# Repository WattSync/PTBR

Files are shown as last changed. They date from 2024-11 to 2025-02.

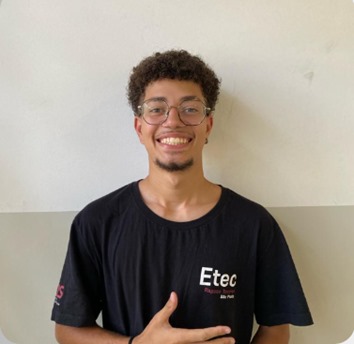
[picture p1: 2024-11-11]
Website/imagens de perfil/perfil bruno.jpg

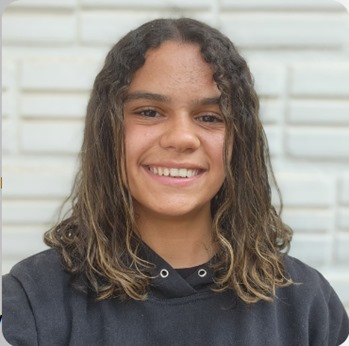
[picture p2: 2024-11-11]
Website/imagens de perfil/camilinha foto.jpg

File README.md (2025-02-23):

# WattSync - Wattímetro Inteligente

O WattSync é um projeto de desenvolvimento de um wattímetro multifuncional que visa atender à crescente demanda por tecnologias de medição e gerenciamento de consumo elétrico em residências. Este dispositivo foi projetado para promover segurança, praticidade e eficiência, oferecendo uma série de funcionalidades que auxiliam no controle do uso de energia.

## 📋 Objetivo do Projeto
Desenvolver um dispositivo capaz de monitorar o consumo de energia elétrica em residências brasileiras, proporcionando acessibilidade e promovendo o controle de gastos com foco em sustentabilidade. O WattSync é voltado para auxiliar os usuários no entendimento e gerenciamento de seu consumo energético, além de fornecer recursos para desligamento remoto e proteção contra sobrecargas.

### Funcionalidades
- Medição de corrente, tensão, potência e frequência com precisão.
- Monitoramento remoto via aplicativo com conexão Wi-Fi.
- Indentificação do tipo de rede elétrica.
- Desligamento automático em caso de sobrecarga.
- Desligamento automático em caso de subtensão ou sobretensão.
- Aviso sonoro em caso de desligamento.
- Limite de consumo configurável.
- Display para a visualização dos dados no própio dispositivo.
- Programação de horários para ligar e desligar os dispositivos.
- Interface amigável para visualizar e interpretar dados de consumo.
- Pode ser utilizado em todas as redes elétricas brasileiras.
## 🛠️ Tecnologias Utilizadas

### Hardware
- **Microcontroladores:** ESP32S3 (WROOM 1) e ATmega328P.
- **Sensores de Corrente e Tensão:** ACS712 30A e Divisor de Tensão.
- **Componentes de Proteção:** Varistor 14D561K, Fusível de Queima Rápida de 25A e Diodo Zener 1N4733A.

### Software
- **Frontend do Aplicativo:** Flutter.
- **Backend:** C (para o ESP32 e ATmega328P).
- **Armazenamento de Dados:** SQLite para o aplicativo.
- **Ferramentas de Design:** Canva, Figma, Paint, Fritzing, KiCad, Astah UML.
- **IDE:** Visual Studio Code, Arduino IDE, Google IDX.
- **Versionamento de Código:** Git, Github.

## 🚀 Como Executar o Projeto

### Pré-requisitos
- [Flutter SDK](https://flutter.dev/docs/get-started/install) para o aplicativo.
- [Arduino IDE](https://www.arduino.cc/en/software) para o ESP32 e ATmega328P.

### Passos para Configuração
1. Clone este repositório:
    ```bash
    git clone https://github.com/usuario/WattSync.git
    cd WattSync
    ```

2. Configure o ambiente de desenvolvimento Flutter:
    ```bash
    flutter pub get
    ```

3. Conecte o ESP32 ao computador e faça upload do código na pasta `ESP32S3` para o ESP32S3 usando a Arduino IDE.
    Selecione a placa "ESP32S3 Dev Module", em outras variações pode não funcionar corretamente.

4. Conecte o ATmega328P ao computador utilizando um gravador UART e faça upload do código na pasta `ATMEGA328P` usando a Arduino IDE.

5. Execute o aplicativo:
    ```bash
    flutter run
    ```

6. No aplicativo, insira o código do produto para acessar as funcionalidades de monitoramento e controle.

## 💡 Estrutura do Projeto

- `app/`: Código do aplicativo Flutter, incluindo widgets e gráficos.
- `wattmeter/ESP32S3/`: Código para o ESP32, responsável por capturar os dados do ATmega328P e enviar ao aplicativo.
- `wattmeter/ATMEGA328P/`: Código para o ATmega328P, responsável por realizar a leitura, calcular os valores e enviar para o ESP32S3.
- `docs/`: Documentação do projeto, incluindo diagramas UML, Canvas do modelo de negócios e relatórios.

Desenvolvido por [Equipe WattSync](https://github.com/WattSync) para o Trabalho de Conclusão de Curso do Técnico em Desenvolvimento de Sistemas da ETEC Raposo Tavares.

### 👷👷‍♀️ Membros da Equipe

- [Beatriz Bernardes](https://www.linkedin.com/in/beatrizbernardess): Responsável pelo desenvolvimento do software e das apresentações.
- [Bruno](https://github.com/usuario/WattSync): Responsável pelo desenvolvimento do website.
- [Camila](https://www.linkedin.com/in/camila-lourenco23032007): Responsável pelo desenvolvimento do software e documentação do projeto.
- [Hércules da S. Pereira](https://www.linkedin.com/in/herculessp): Responsável pelo desenvolvimento e planejamento do software e hardware do dispositivo.
- [Keven Wanne](http://www.linkedin.com/in/keven-wanne): Responsável pelo desenvolvimento do software.
- [Yasmin E. P. da Silva](https://www.linkedin.com/in/yasminpilla): Responsável pelo desenvolvimento do software e documentação do projeto.

## 📝 Licença

Este projeto está licenciado sob a Licença GPL-3.0. Veja o arquivo [LICENSE](./LICENSE) para mais detalhes.

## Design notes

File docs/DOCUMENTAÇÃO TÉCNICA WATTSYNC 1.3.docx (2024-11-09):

TRABALHO DE CONCLUSÃO DE CURSO (TCC)

WATTSYNC

DOCUMENTAÇÃO TÉCNICA DO DISPOSITIVO

(VERSÃO 1.3)

São Paulo – SP

2024

O presente documento não se trata da monografia oficial do trabalho de conclusão de curso, portanto, não se faz necessário a utilização da formatação da Associação Brasileiras de Normas Técnicas (ABNT), entretanto, será utilizada parcialmente com o objetivo de facilitar a organização.

# 1 Componentes gerais

## 1.1 Capacitor

Um capacitor é um componente que armazena energia elétrica em um campo elétrico, consistindo em duas placas condutoras separadas por um material isolante. Ele é utilizado para filtrar ruídos, suavizar flutuações de tensão e armazenar energia em circuitos. A capacitância, medida em farads (F), determina a quantidade de carga que o capacitor pode armazenar e sua capacidade de desacoplamento.

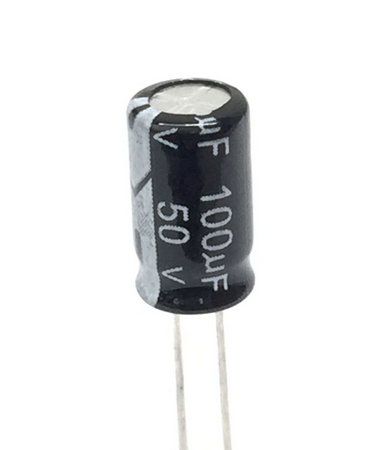
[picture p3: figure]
Capacitor Eletrolítico 100uF 50V

Figura 1 - Capacitor.

## 1.2 Resistor

Um resistor é um componente que oferece resistência ao fluxo de corrente elétrica. Ele é utilizado para limitar a corrente, dividir tensões e proteger componentes sensíveis. Os resistores têm valores de resistência, medidos em ohms (Ω), e podem ser fixos ou variáveis, permitindo ajustes em circuitos.

Figura 2 - Resistor

## 1.3 Trimpot

Um trimpot, ou potenciômetro de ajuste, é um resistor variável ajustável manualmente. Ele é utilizado em circuitos para calibrar e ajustar parâmetros, como níveis de tensão. Trimpots são menores e têm um mecanismo de ajuste que permite a regulagem com uma chave de fenda, facilitando ajustes finos.

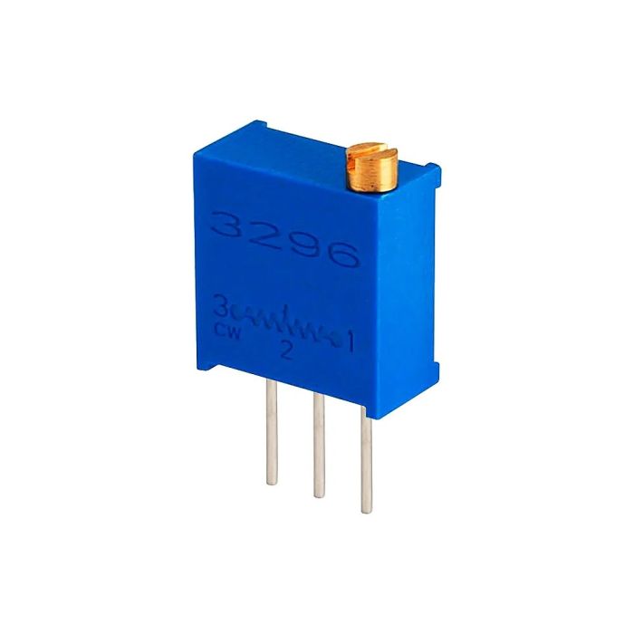
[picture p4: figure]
Trimpot Multivoltas 25 Voltas 3296W Vertical 500R Ohm

Figura 3 – Trimpot.

## 1.4 Diodo

Um diodo é um componente eletrônico que permite que a corrente elétrica flua em uma única direção, funcionando como uma válvula. Ele é usado em circuitos para retificação, proteção contra polaridade reversa e controle de sinais. Um diodo tem dois terminais: ânodo (positivo) e cátodo (negativo). Ele conduz corrente quando a tensão no ânodo é maior que no cátodo.

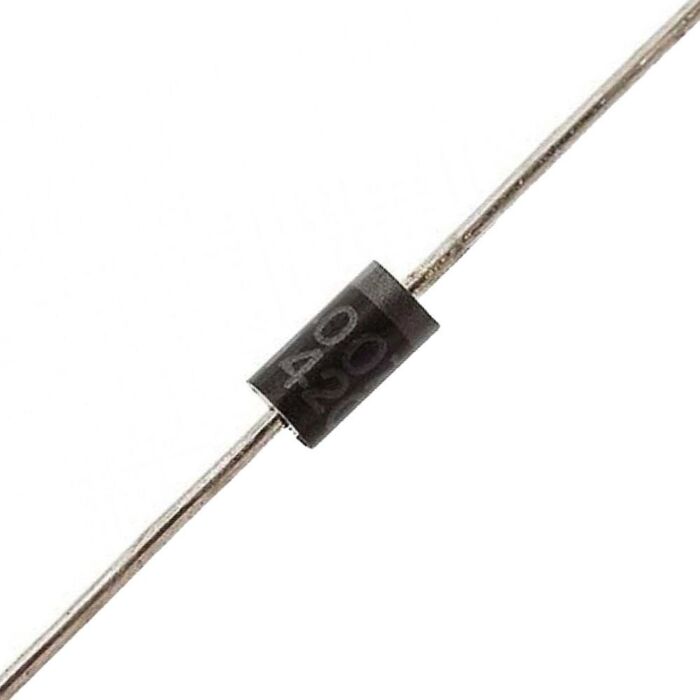
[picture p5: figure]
Componentes Eletrônicos você encontra aqui na Mamute Eletrônica | Diodo Retificador 1N4937 DO-41 600V 1A.

Figura 4 - Diodo.

### 1.4.1 Diodo Zener

O diodo Zener é uma variação do diodo projetado para operar em polarização reversa, permitindo a condução de corrente quando a tensão reversa atinge um nível específico, chamado tensão Zener. Ele é usado como regulador de tensão em circuitos, garantindo que a tensão permaneça constante, mesmo com variações na entrada. É fundamental em circuitos de proteção e estabilização.

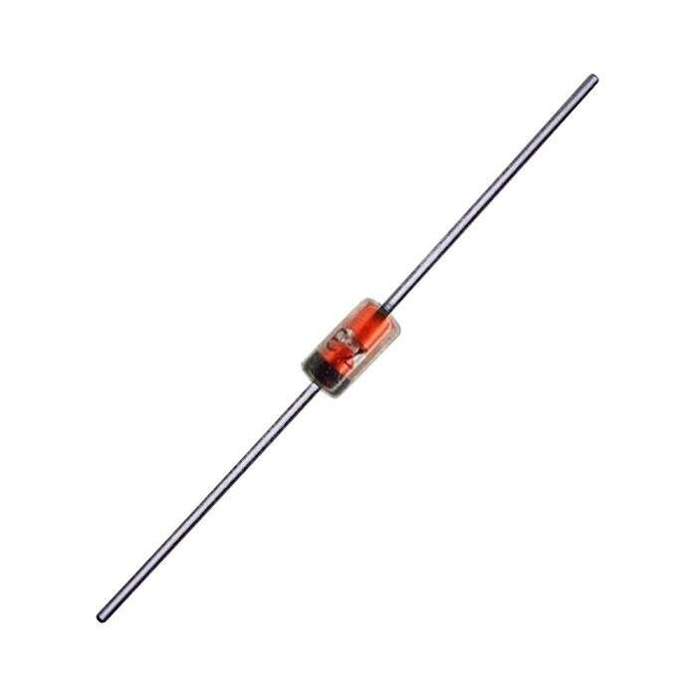
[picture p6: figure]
Diodo zener 1/2w - 5v1

Figura 5 - Diodo Zener.

## 1.5 Transistor NPN

Um transistor NPN é um tipo de transistor bipolar formado por três camadas semicondutoras: duas de material tipo N (negativo) e uma de material tipo P (positivo). Ele possui três terminais: Coletor (C), Base (B) e Emissor (E). O funcionamento do transistor NPN se baseia na polarização da base, que controla a corrente entre o coletor e o emissor. Quando a base é polarizada positivamente, ela permite que uma corrente maior flua do coletor para o emissor, funcionando como um amplificador de sinal.

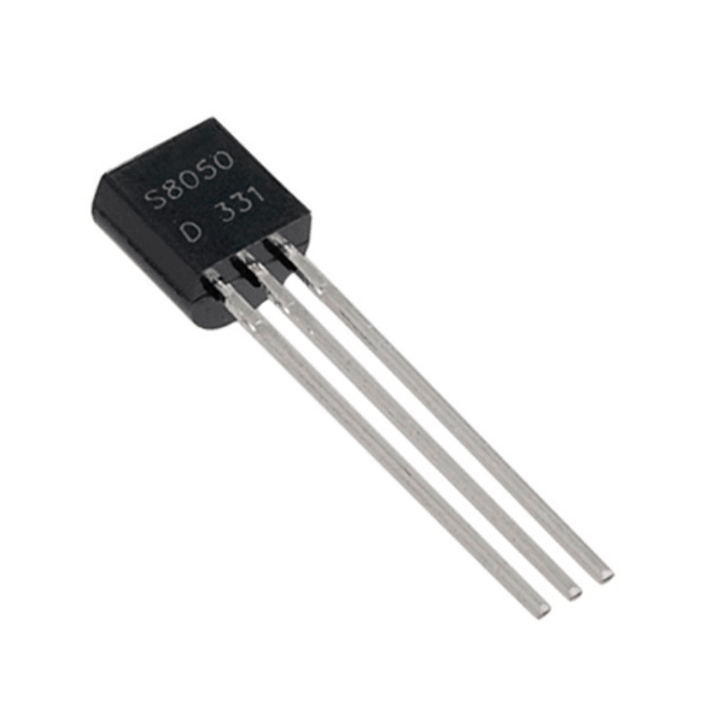
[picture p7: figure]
Transistor NPN S8050 TO-92 (PTH)

Figura 6 - Transistor NPN.

# 2 sistema de alimentação

## 2.1 Fonte de alimentação

Para que o projeto funcione, é necessário transformar a tensão alternada da tomada em baixa tensão contínua, para isso é utilizado a fonte de alimentação Hi-Link HLK-5M05, sendo bivolt, funcionando com tensão entre 100 e 240 volts, com saída de 5 volts e 1 ampère.

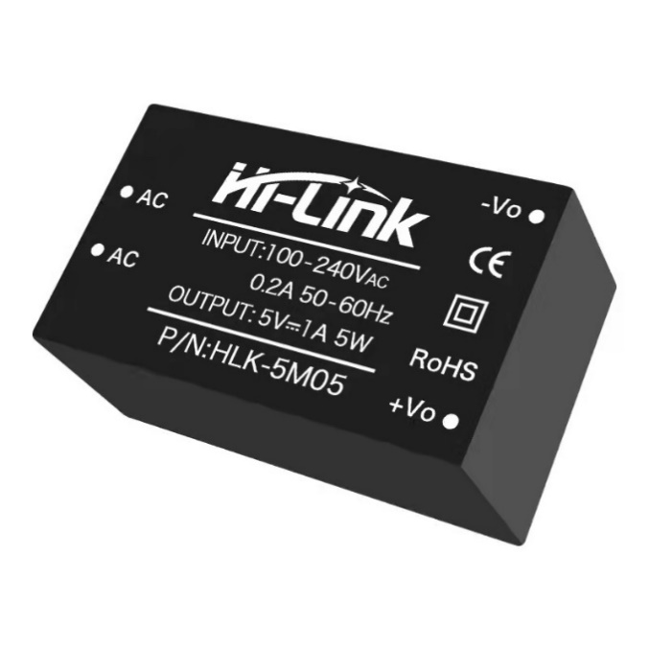
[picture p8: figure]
Mini Fonte Conversora Ac/dc Hi-link Hlk-5m05 5v 5w

Figura 7 - Fonte de alimentação HLK-5M05

## 2.2 Regulador de tensão

Dada a necessidade de garantir que a tensão de funcionamento de alguns componentes permaneça dentro dos limites adequados, é essencial implementar um sistema de regulação de tensão. Para isso, foi escolhido o regulador de tensão 3.3V AMS1117, conhecido por sua alta eficiência e capacidade de fornecer uma saída estável. Para estabilizar a tensão, foi adicionado um capacitor eletrolítico de 300uf antes do regulador e um de 100uf pós regulador.

Figura 8 - AMS1117.

## 2.3 Varistor

Para a proteção do circuito contra sobretensões, foi utilizado um varistor 14D561K, instalado entre a fase e o neutro. Este componente é projetado para absorver picos de tensão, desviando correntes excessivas para o outro condutor e, assim, protegendo os circuitos e dispositivos conectados. O varistor atua como uma barreira, evitando que tensões acima de um certo limiar atinjam componentes sensíveis, o que é crucial para garantir a integridade e a durabilidade do sistema. A escolha do varistor 14D561K se baseia em sua tensão de ruptura ser a mais próxima da necessária, proporcionando uma camada adicional de segurança ao circuito.

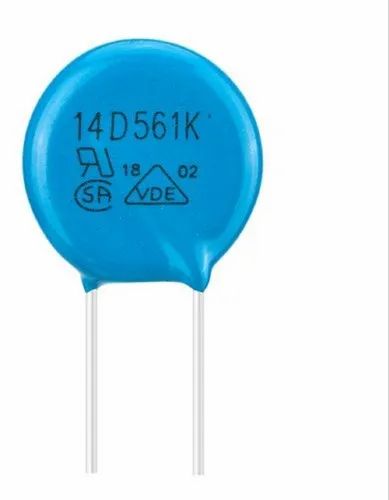
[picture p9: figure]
600V RMS HEL-14D561K at Rs 2/piece in Mumbai | ID: 2853572355062

## 2.4 Fusível

Caso o varistor atue ou a proteção eletrônica presente no dispositivo seja acionada, o fusível se rompe, desconectando o circuito e prevenindo danos aos componentes. Para essa aplicação, foi escolhido um fusível de queima rápida de 25A, dimensionado para as necessidades do projeto. Este tipo de fusível é projetado para reagir rapidamente a sobrecargas e curtos-circuitos, interrompendo imediatamente o fluxo de corrente.

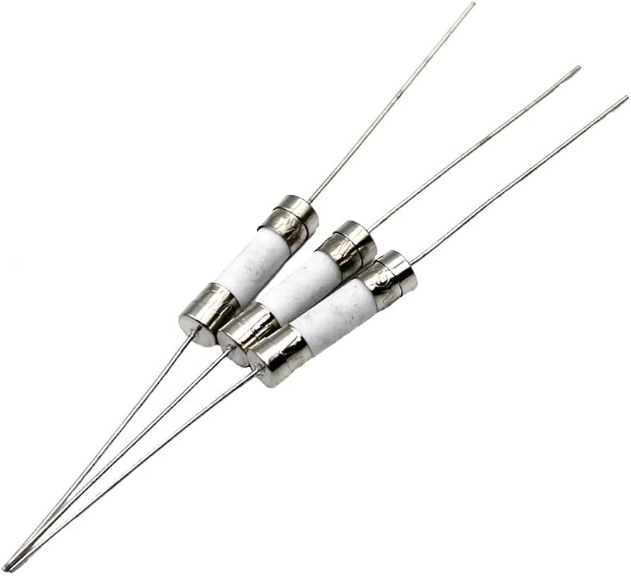
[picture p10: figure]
10PCS 5 * 20mm Ceramic Fuse with a pin 250V,Fast Break F,25A : Amazon.com.au: Home Improvement

Figura 9 - Fusível 25A

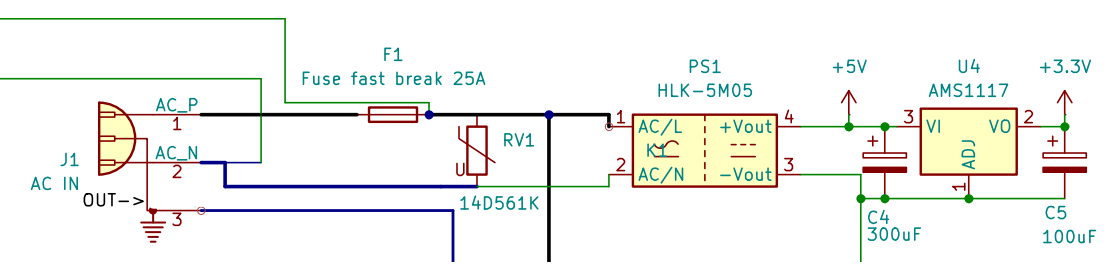
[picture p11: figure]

Figura 10 - Esquema de ligação do sistema de alimentação.

# 3 sistema de conexão e exibição

## 3.1 Microcontrolador

O microcontrolador utilizado no desenvolvimento do projeto é o ESP32 WROOM-1, um módulo altamente eficiente, com 45 portas GPIO (General Purpose Input/Output), permitindo uma ampla gama de funcionalidades, como controle de periféricos externos, sensores e atuadores. Ele também suporta modulação por largura de pulso (PWM), permitindo o controle preciso de dispositivos como motores, LEDs e outros componentes. O ESP32 WROOM-1 destaca-se por sua capacidade de comunicação sem fio através de Wi-Fi, facilitando a transmissão de dados em tempo real com o aplicativo. Isso elimina a necessidade de conexões físicas, proporcionando flexibilidade e permitindo o desenvolvimento de soluções inovadoras para automação e IoT.

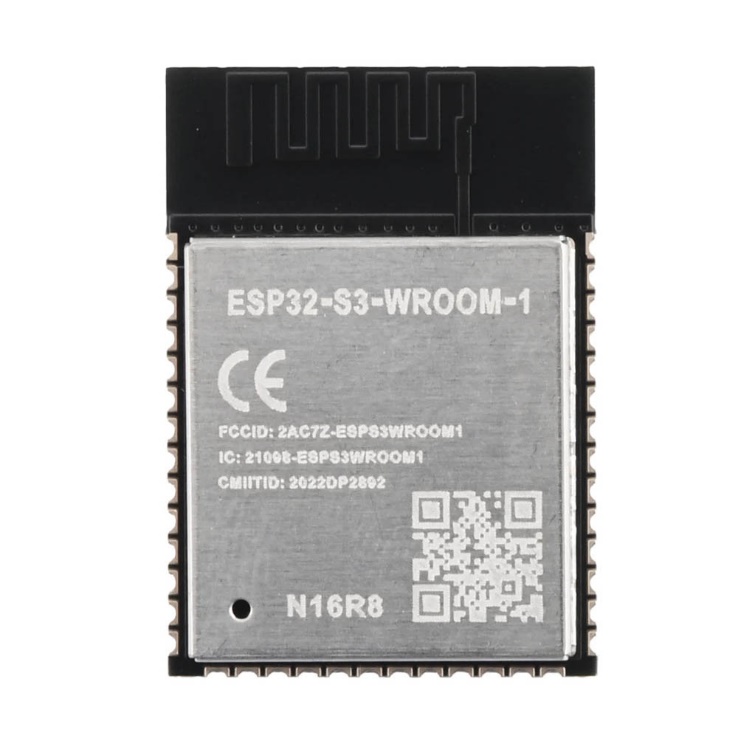
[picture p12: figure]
Módulo ESP32-S3 - ESP32-S3-WROOM-1 N16R8

Figura 11 - Esp32-wroom-1.

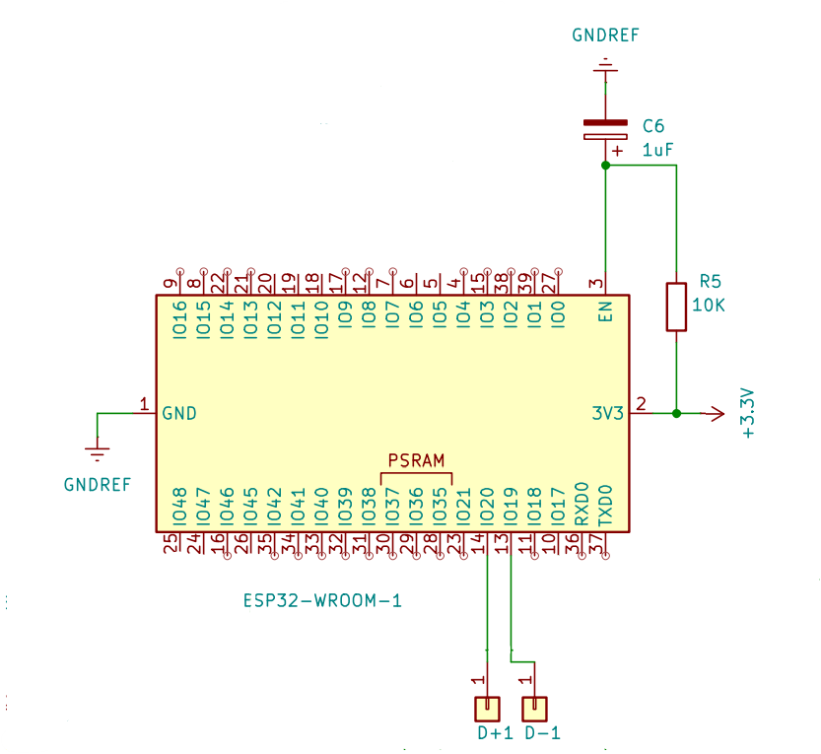
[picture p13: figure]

Figura 12 - Esquema de ligação do Esp32-wroom-1.

## 3.2 Tela

Para que não haja a necessidade de abrir o aplicativo no smartphone apenas para visualizar as informações de consumo, o dispositivo conta com um display TFT de 1.8 polegadas colorido e com resolução de 128 pixels de largura por 160 pixels de altura. Não é utilizado o slot para cartão de memória incluído no display. Utiliza o protocolo de comunicação SPI e possui os pinos: Light Emitting Diode (Led), Serial Clock (SCK), Master Input Slave Output (MOSI)[^1], Data/Command (DC)[^2], Reset (RST), Slave Select (CS), Graduated Neutral Density Filter (GND) e Voltage at the Common Collector (VCC).

Ligações:

LED: Conectado a linha positiva de 3.3 Volts;

SCK: conectado ao GPIO 12;

MOSI: conectado ao GPIO 11;

DC: conectado ao GPIO 6;

RST: conectado ao GPIO 5;

CS: Conectado ao GPIO 10;

GND: Conectado diretamente ao polo negativo;

VCC: Conectado a linha positiva de 3.3 Volts.[^3]

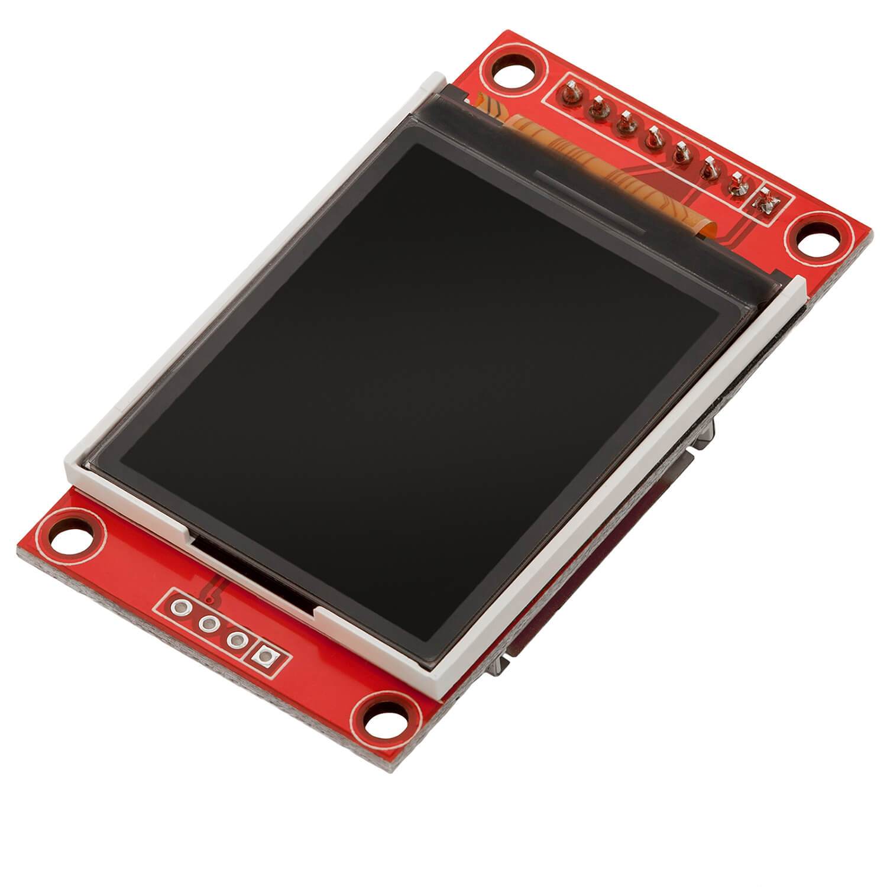
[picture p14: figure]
1.8 inch Spi TFT Display ST7735 with 128 x 160 pixels

Figura 13 - Display 1.8 TFT.

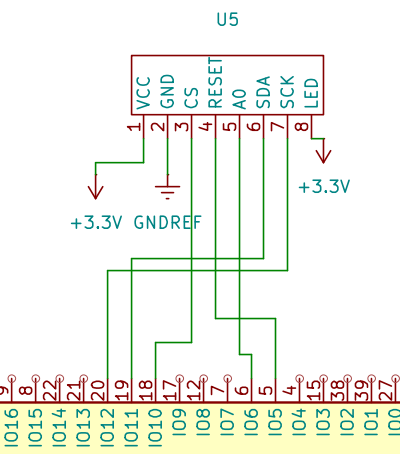
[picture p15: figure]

Figura 14 - Esquema de ligação do display.

## 3.3 Aviso sonoro e jingle

Caso ocorra de o dispositivo entrar em modo de proteção, seja por excesso de corrente ou tensão incorreta, o usuário deve ser alertado de maneira ostensiva, para isso utiliza-se um buzzer, que consiste em um piezoelétrico que dilata e emite som caso receba energia em determinada frequência, como o buzzer necessita de 5V e cada GPIO fornece no máximo 3.3V, será utilizado um transistor NPN com um resistor de 1KΩ em sua base.

O buzzer também desempenha a função de emitir uma curta melodia quando o dispositivo é iniciado.

Ligação:

RESISITOR: Conectado ao GPIO 17;

B: Conectado ao resistor;

C: Conectado ao GND do buzzer;

E: Conectado ao GND;

VCC: Conectado ao polo positivo de 5V.

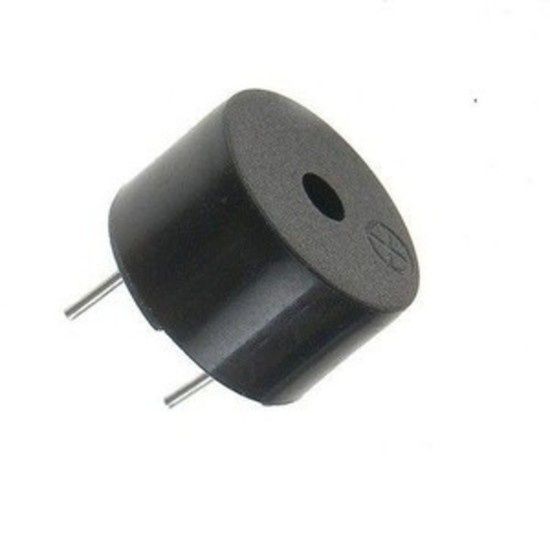
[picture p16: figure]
Buzzer Passivo 5v

Figura 15 - Buzzer passivo.

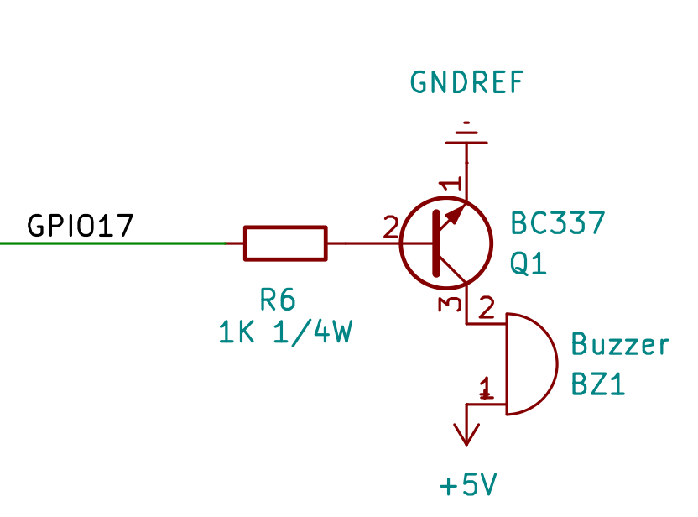
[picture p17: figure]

Figura 16 - Esquema de ligação do sistema de aviso sonoro.

## 3.4 Integração ao ATmega328P

Para a comunicação entre o Esp32 e o ATmega328P ser possível era necessário algum conversor de tensão, já que os dois microcontroladores operam com tensões de nível lógico diferentes, 3.3V e 5V, respectivamente, para solucionar esse problema, foi inserido um divisor de tensão, sendo composto por um resistor de 2kΩ e um resistor de 1KΩ, assim reduzindo de 5V para 3.3.V.

Ligação:

Resistor de 2KΩ: Conectado ao GND e ao resistor de 1KΩ.

Resistor de 1KΩ: Conectado ao pino PD3 do ATmega328P e ao resistor de 2KΩ.

Ponto entre os dois resistores: Conectado ao GPIO47 do Esp32.

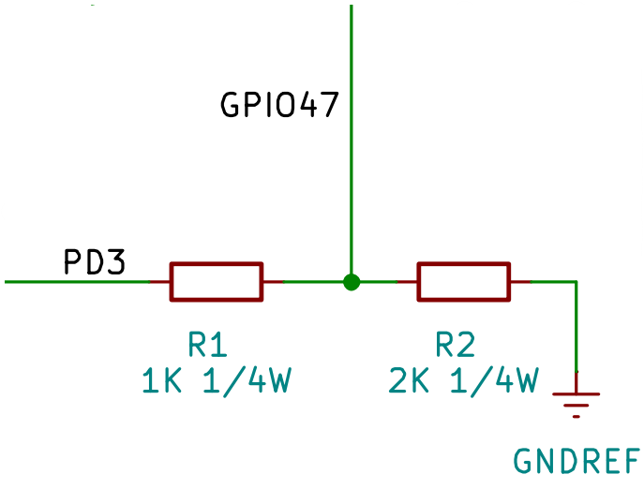
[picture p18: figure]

Figura 17 - Esquema de ligação entre os microcontroladores.

# 4 sistema de medição e gerenciamento de saída

## 4.1 Microcontrolador

O ATmega328P é um microcontrolador de 8 bits da família AVR, amplamente utilizado em projetos de eletrônica e sistemas embarcados devido à sua eficiência e custo acessível. Ele possui 32KB de memória flash para armazenamento de código, 2KB de memória RAM e 1KB de EEPROM, ideal para armazenamento de dados não voláteis. O ATmega328P opera a uma frequência de até 20MHz e possui 23 pinos de entrada e saída (I/O), com suporte a interfaces como I2C, SPI e UART, o que facilita a comunicação com outros dispositivos.

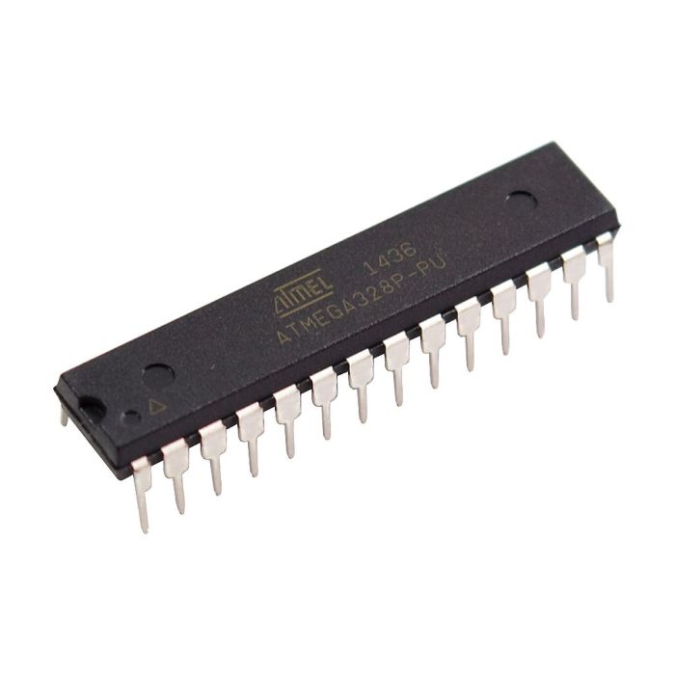
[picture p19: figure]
Microcontrolador ATmega328P DIP28

Figura 18 - ATmega328P.

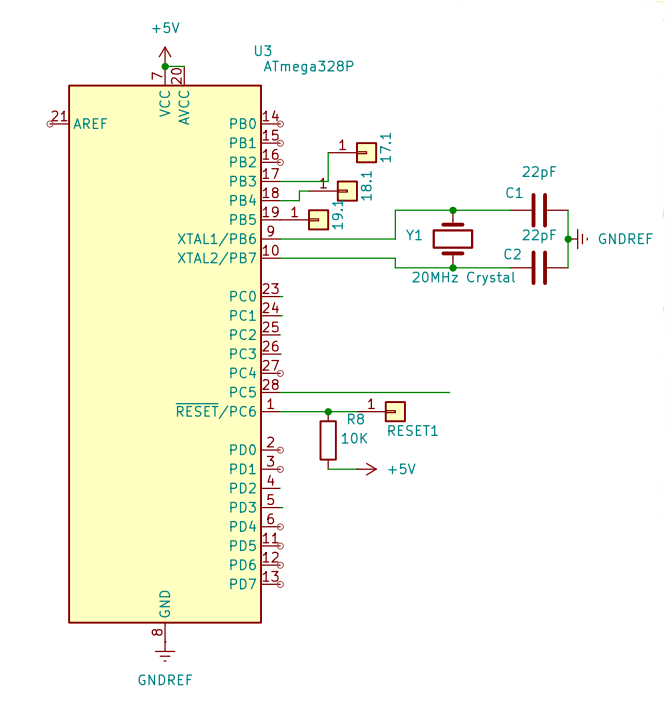
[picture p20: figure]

Figura 19 - Esquema de ligação do ATmega328P.

## 4.2 Sensor de corrente

Para que seja possível calcular o consumo dos equipamentos elétricos, se faz necessário obter a potência (W) que cada equipamento está consumindo, valor esse que é o resultado da multiplicação da corrente (A) e da tensão (V). O sensor utilizado para medir a corrente foi o ACS712, ele precisa de 5 conexões, sendo o VCC, GND, a saída chamada de OUT e os dois últimos são conectados à rede elétrica, um no fio fase da tomada e o outro no fio fase do equipamento a ser medido.

Ligações:

GND: Conectado ao polo negativo;

VCC: Conectado ao polo positivo de 5V.

OUT: Conectado a A0 do ATmega328P;

L-in: Conectado ao fio fase da tomada;

L-out: Conectado ao fio fase do equipamento.

Figura 20 - Sensor de corrente ACS712 30A.

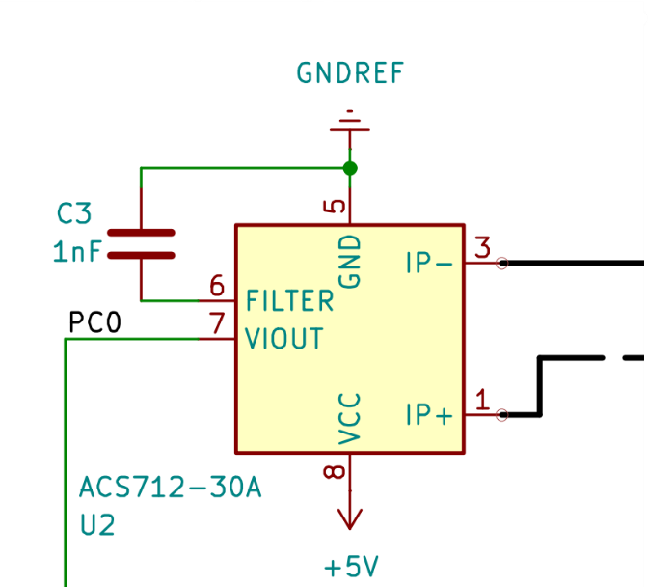
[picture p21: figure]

Figura 21 - Esquema de ligação do sensor de corrente.

## 4.3 Sensor de tensão

Para medir a grandeza que falta, é necessário um módulo ou esquema elétrico, inicialmente foi escolhido um módulo de tensão, mas depois de realizar cálculos com a fórmula do divisor de tensão, foi decidido que essa seria a estratégia adotada, com menor custo e realizando a mesma função e até com maior precisão que o módulo. Esse sistema consiste em 1 resistor de determinado valor conectado a um dos fios da rede elétrica, a outra ponta conectado a um trimpot e esse trimpot conectado ao GND, o valor do trimpot definido foi 20kΩ. Para realizar essa medição, é necessário compreender como funciona o sistema de tensão alternada: O sistema de tensão alternada doméstico pode possuir até 3 fios: duas fases anguladas em 120° cada e um neutro, que é aterrado para equilibrar as fases. Dependendo do estado, a tensão fase-neutro é de 127V e fase-fase corresponde a 220V, já em outros locais[^4], a tensão entre fase-neutro é de 220V, tendo apenas esses dois fios. O sistema funciona com ondas senoidais, com tensão eficaz (RMS) e tensão de pico, antes de calcular o resistor correto, é preciso descobrir a tensão de pico, dada a expressão:

V_p =V_(rms) ×√2

Substituindo, temos:

V_p =220×1,41

Então, Vp=311 , sabendo a tensão de pico, deve-se escolher a tensão que deverá ser obtida através do divisor, baseando-se no intervalo de tensão do ADC do ATmega328P, foi escolhido para média de tensão 5V quando Vp = 311V e utilizando metade da resistência do trimpot. A fórmula do divisor de tensão dá-se em:

V_(out) =(R_2)/(R_1 +R_2)×V_(in)

Organizando para descobrir R1, temos:

R1=R2×((V_(in))/(V_(out))-1)

Substituindo os termos por valores já conhecidos:

R1=10kΩ×((311V)/(5V)-1)

Então R1=620kΩ . Para descobrir qual o valor mínimo de R1, repete-se a fórmula, agora com R2 com o valor de 20KΩ
R1=20kΩ×((311V)/(5V)-1)

Então R1=1,3MΩ . Descontando 10% de margem de erro por causa dos resistores, então a faixa de resistores possíveis para o projeto está entre 620kΩ e 1,17MΩ. Com os valores de resistores já encontrados, o ponto médio entre o resistor e o trimpot deve ser conectado a entrada PC2 do ATmega328P. O mesmo circuito deve ser repetido no outro fio da rede elétrica e o ponto médio conectado a entrada analógica PC3. Por fim, deve-se calibrar o dispositivo com o auxílio de um voltímetro medindo a diferença de potencial entre cada ponto médio e o solo girando o trimpot. Para a proteção do circuito, há um diodo zener com tensão de ruptura em 5.1V, com o cátodo conectado ao divisor de tensão e o ânodo ao negativo.

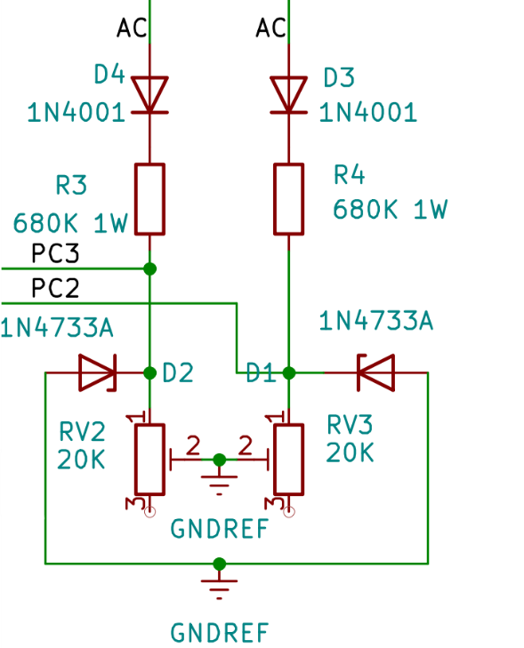
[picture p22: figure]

Figura 22 - Sensor de tensão.

## 4.4 Sistema de desligamento de carga

Para proteger os equipamentos acoplados ao WattSync e até mesmo os sensores do próprio dispositivo, deve existir uma maneira de parar e iniciar o fornecimento de energia, isso é feito através do relé, um dispositivo eletromecânico que possui 4 terminais, o Common (COM), Normally Open (NO), VCC e GND. O relé utilizado será de 30A com acionamento 5V através de um transistor NPN acoplado a um resistor de 1KΩ. O sistema também possui um diodo entre os terminais da bobina para drenar a tensão reversa gerada ao desligar o relé.

Ligação:

RESISTOR: Conectado ao PD2;

B: Conectado resistor;

C: Conectado ao GND do relé;

E: Conectado ao GND.

NO: Conectado a fase da tomada;

COM: Conectado a fase do equipamento;

VCC: Conectado ao polo positivo de 5V;

Cátodo: Conectado ao polo positivo de 5V;

Ânodo: Conectado ao polo negativo.

Figura 23 - Relé 05VDC 30A

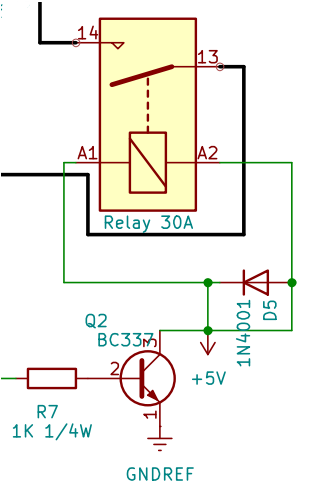
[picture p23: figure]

Figura 24 - Esquema de ligação do sistema de desligamento de carga.

# 5 Esquema de ligação completo

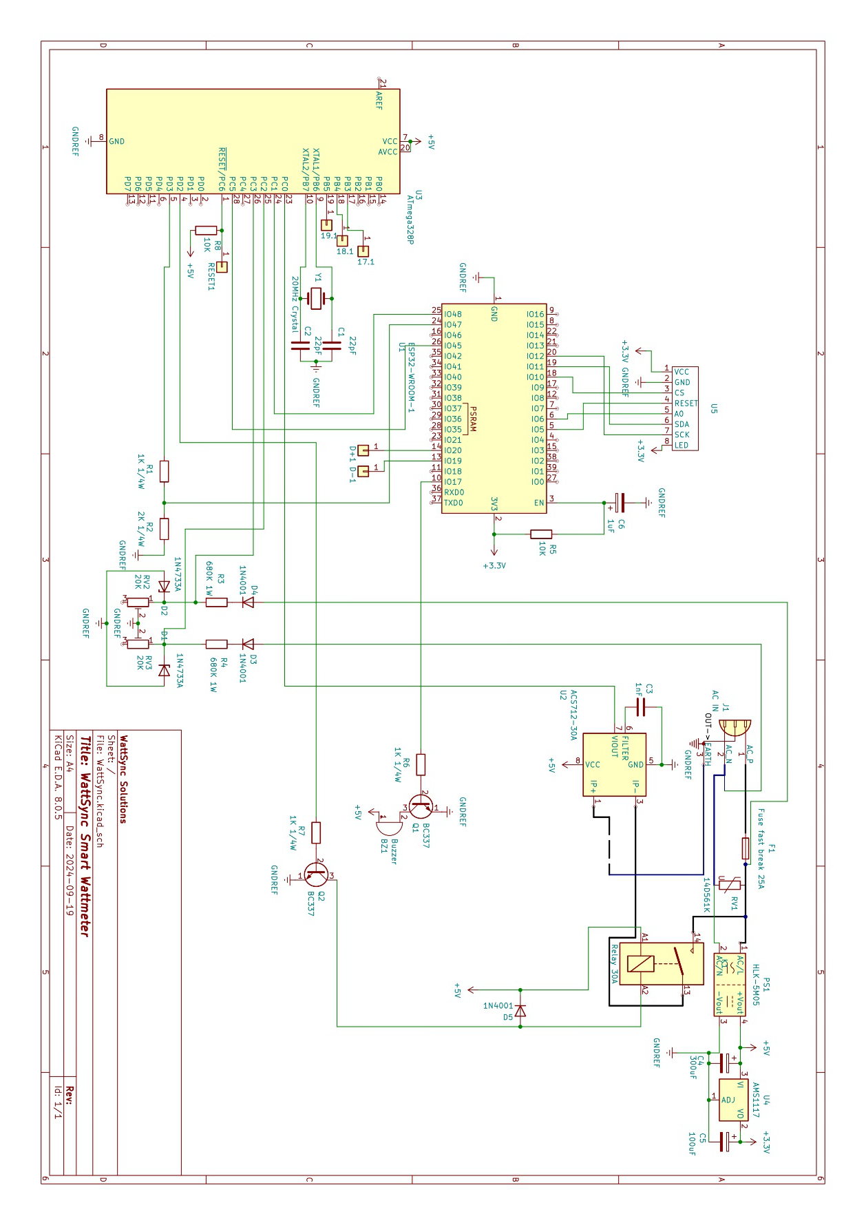
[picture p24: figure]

Figura 25 - Esquema completo de ligação do dispositivo WattSync.

# 6 Esquema de ligação do circuito impresso

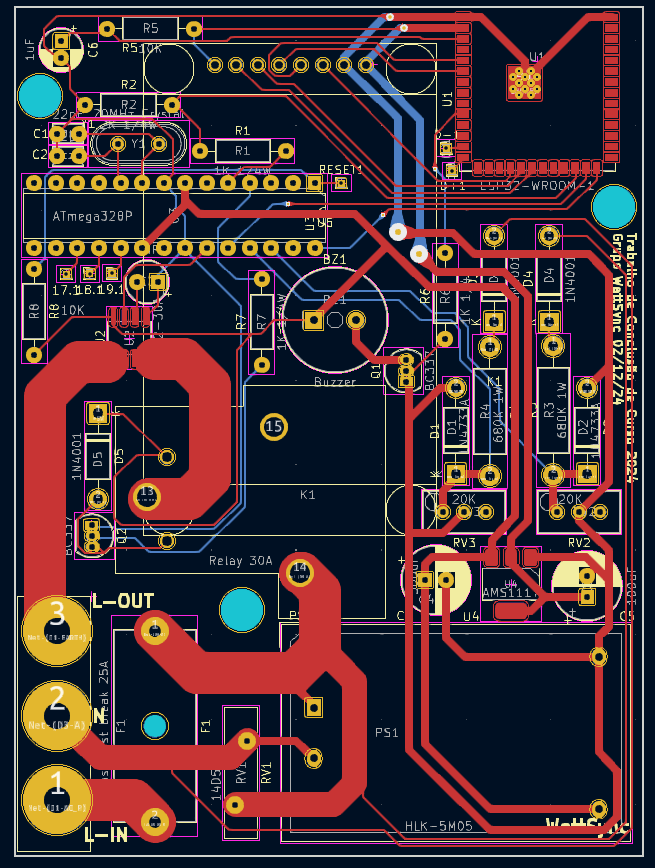
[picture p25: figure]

Figura 26 - Esquema de ligação do circuito impresso.

# 7 Modelo 3d

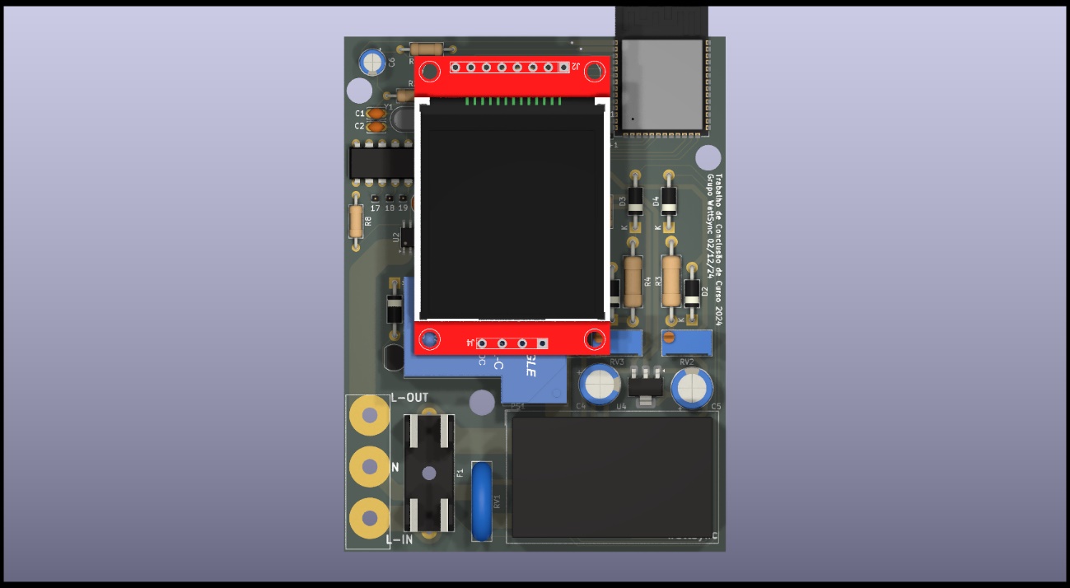
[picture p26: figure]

Figura 27 - Modelo 3D do dispositivo WattSync.

# 8 Lista de Componentes

Referência | Nome | Valor Un | Quantidade | Valor
BZ1 | Buzzer Passivo | R$ 0,93 | 1 | R$ 0,93
C1, C2 | Capacitor cerâmico 22pF | R$ 0,05 | 2 | R$ 0,10
C3 | Capacitor cerâmico 1nF | R$ 0,05 | 1 | R$ 0,05
C4 | Capacitor eletrolítico 300uF | R$ 0,70 | 1 | R$ 0,70
C5 | Capacitor eletrolítico 100uF | R$ 0,50 | 1 | R$ 0,50
C6 | Capacitor eletrolítico 1uF | R$ 0,30 | 1 | R$ 0,30
D1, D2 | Diodo zener 1N4733A | R$ 0,11 | 2 | R$ 0,22
D3, D4, D5 | Diodo 1N4001 | R$ 0,10 | 3 | R$ 0,30
F1 | Fusível fast break 25A | R$ 1,04 | 1 | R$ 1,04
K1 | Relé 05VDC 30A | R$ 8,96 | 1 | R$ 8,96
PS1 | HLK-5M05 | R$ 15,75 | 1 | R$ 15,75
Q1, Q2 | Transistor NPN BC337 | R$ 0,15 | 2 | R$ 0,30
R1, R6, R7 | Resistor 1K 1/4W | R$ 0,08 | 3 | R$ 0,24
R2 | Resistor 2K 1/4W | R$ 0,08 | 1 | R$ 0,08
R3, R4 | Resistor 680K 1W | R$ 0,40 | 2 | R$ 0,80
R5, R8 | Resistor 10K | R$ 0,08 | 2 | R$ 0,16
RV1 | Varistor 14D561K | R$ 1,06 | 1 | R$ 1,06
RV2, RV3 | Trimpot 20K | R$ 1,04 | 2 | R$ 2,08
U1 | ESP32-WROOM-1 | R$ 23,96 | 1 | R$ 23,96
U2 | ACS712-30A | R$ 7,27 | 1 | R$ 7,27
U3 | ATmega328P | R$ 16,35 | 1 | R$ 16,35
U4 | AMS1117 | R$ 2,56 | 1 | R$ 2,56
U5 | Display 1.8 TFT | R$ 16,66 | 1 | R$ 16,66
Y1 | Cristal Oscilador 20MHz | R$ 0,83 | 1 | R$ 0,83
| Placa Fenolite 10x15cm | R$ 4,35 | 1 | R$ 4,35
| Total | | | R$ 105,55

[^1] No display utilizado, o pino MOSI vem com a serigrafia SDA.
[^2] No display utilizado, o pino DC vem com a serigrafia A0.
[^3] O display possui a faixa de tensão entre 3.3V-5V
[^4] Esse fato ocorre principalmente na região nordeste do Brasil.

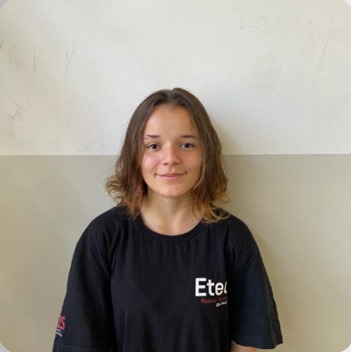
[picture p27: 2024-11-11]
Website/imagens de perfil/perfil yasmin.jpg

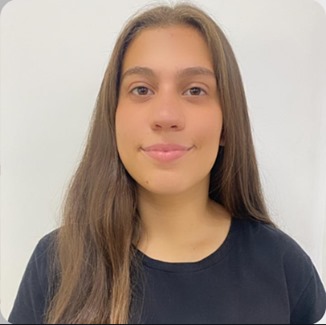
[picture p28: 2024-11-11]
Website/imagens de perfil/perfil bia.jpg

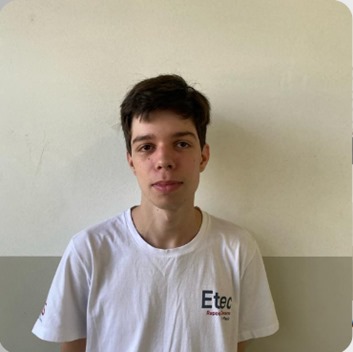
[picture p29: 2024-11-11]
Website/imagens de perfil/perfil hercules.jpg

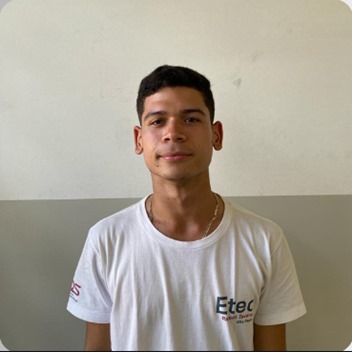
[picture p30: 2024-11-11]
Website/imagens de perfil/perfil wanne.jpg

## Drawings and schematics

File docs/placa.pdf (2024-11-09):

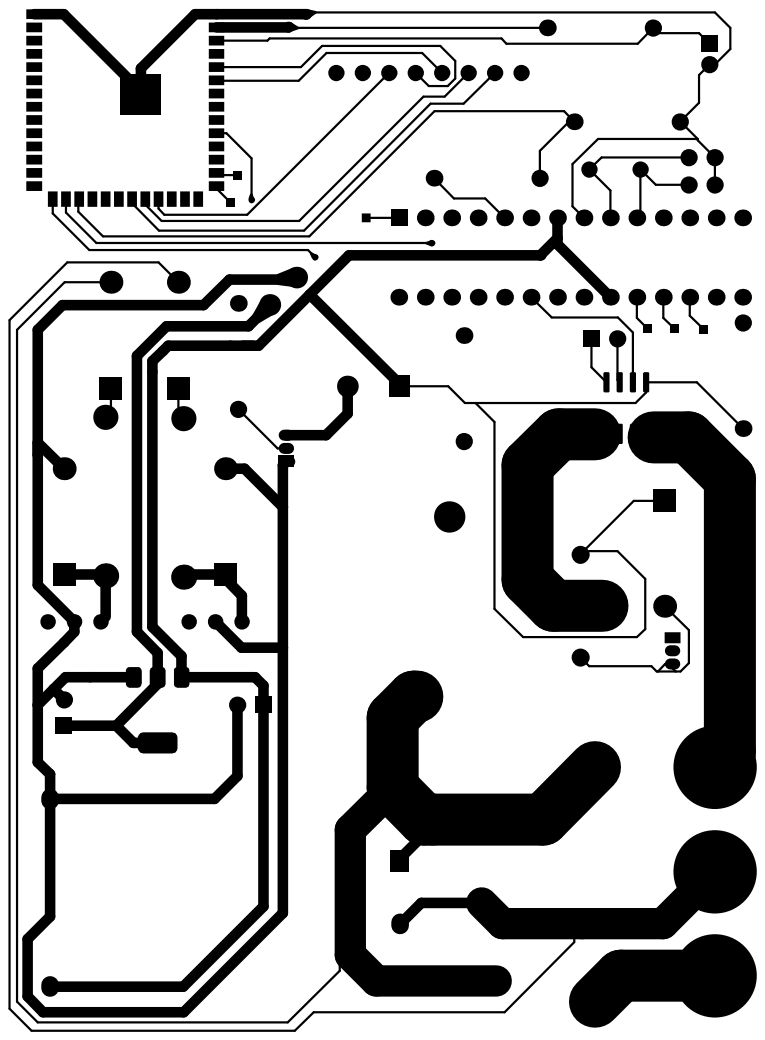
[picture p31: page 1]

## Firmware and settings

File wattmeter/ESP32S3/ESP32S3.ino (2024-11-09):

#include <WiFi.h>
#include <WiFiManager.h>
#include <WebServer.h>
#include <ArduinoJson.h>
#include <ESPmDNS.h>
#include <Adafruit_GFX.h>
#include <Adafruit_ST7735.h>
#include <EEPROM.h>
#include "screens.h"
#include "HardwareSerial.h"

#define BUZZER_PIN      17
#define TFT_CS          10
#define TFT_RST         5
#define TFT_DC          6
#define TX_PIN          40
#define RX_PIN          47
#define TRANSMITTER_PIN 48

// Definições para o wear leveling da EEPROM
const int EEPROM_SIZE = 512;  // Tamanho da EEPROM a ser usado
const int MAX_WRITES = 10; // Número máximo de escritas
int startAddress = 0;         // Endereço inicial para o wear leveling
int writeCounts = 0;          // Contador de escritas

// Endereços de memória para as variáveis
const int enderecoTema = 0;   // Endereço para a variável 'tema'
const int enderecoBrilho = 4; // Endereço para a variável 'brilho'

Adafruit_ST7735 tft = Adafruit_ST7735(TFT_CS, TFT_DC, TFT_RST);

WebServer server(80); // 80 é a porta padrão para HTTP
HardwareSerial mySerial(1); // UART1

float Voltage, Voltage_Wire_1, Voltage_Wire_2, Current, ValueInReal, Frequency, ValuePowerLimit = 0;
float Power = Voltage * Current;
float ValueTotal = Power /1000 * ValueInReal;
bool PowerLimitDisplay, Wire_1, Wire_2, ON = 0;
int error = 0;
bool tema = true;
bool alreadyExecuted = false;
uint16_t Color;

uint16_t DarkColors [8] = {
  ST7735_WHITE,
  ST7735_MAGENTA,
  ST7735_RED,
  ST7735_YELLOW,
  ST7735_GREEN,
  ST7735_WHITE,
  ST7735_WHITE,
  ST7735_GREEN
};

uint16_t LightColors [8] = {
  ST7735_BLACK,
  ST7735_BLUE,
  ST7735_RED,
  ST7735_ORANGE,
  ST7735_GREEN,
  ST7735_BLACK,
  ST7735_BLACK,
  ST7735_GREEN
};

int FontSize [8] = {1, 1, 1, 1, 1, 2, 1, 1};

int X [8] = {17, 5, 78, 5, 78, 10, 17, 97};
int Y [8] = {1, 26, 26, 53, 53, 80, 115, 115};

int tonee [4] = {494, 622, 740, 988};
int delayy [4] = {200, 200, 200, 500};

void setup() {
  Serial.begin(115200);
  mySerial.begin(115200, SERIAL_8N1, RX_PIN, TX_PIN);
  pinMode(BUZZER_PIN, OUTPUT);
  pinMode(TRANSMITTER_PIN, OUTPUT);

  // Lê os valores da EEPROM
  tema = EEPROM.read(startAddress + enderecoTema);

  tft.initR(INITR_BLACKTAB);
  tft.setRotation(2);
  delay(500);
  tft.fillScreen(ST7735_BLACK);

  inicializaDisplay();

  WiFiManager wifiManager;
  wifiManager.setTitle("Conecte-se ao dispositivo");
  wifiManager.setHostname("WattSync");

  std::vector<const char *> customMenu = {"wifi", "exit"}; 
  wifiManager.setMenu(customMenu);

  wifiManager.setCustomHeadElement(
    "<style>"
    "button {"
    "  border-radius: 15px;" 
    "  padding: 10px 20px;"
    "  background-color: #800080;" 
    "  color: white;"
    "  border: none;"
    "}"
    "</style>"
  );

  wifiManager.autoConnect("WattSync");

  wifiManager.autoConnect("WattSync");
  if (WiFi.status() == WL_CONNECTED) {
    Serial.println("Conectado ao Wi-Fi.");
    Serial.println(WiFi.localIP());

    if (!MDNS.begin("WattSync")) {
      Serial.println("Erro ao iniciar o serviço mDNS.");
    } else {
      Serial.println("Serviço mDNS iniciado.");
    }

    server.on("/receber-dados", HTTP_POST, handleReceberDados);
    server.on("/enviar-dados", HTTP_GET, handleEnviarDados); 
    server.begin();
  } else {
    Serial.println("Não foi possível conectar ao Wi-Fi.");
  }

  EEPROM.begin(EEPROM_SIZE);

  // Lê o contador de escritas e o endereço inicial da última posição da EEPROM
  startAddress = EEPROM.read(EEPROM_SIZE - 4);
  writeCounts = EEPROM.read(EEPROM_SIZE - 2);

  // Se o contador de escritas atingiu o máximo, reinicie-o e mude o endereço inicial
  if (writeCounts >= MAX_WRITES) {
    startAddress += 6; // Mova para o próximo conjunto de endereços
    if (startAddress >= EEPROM_SIZE - 4) {
      startAddress = 0; // Volte para o início se atingir o fim da EEPROM
    }
    writeCounts = 0;
  }

  
}

void loop() {
  server.handleClient();
  ReciverData();
  //Serial.print("V1: "); Serial.println(Voltage_Wire_1);
  //Serial.print("V2: "); Serial.println(Voltage_Wire_2);
  //Serial.print("I: "); Serial.println(Current);
  //Serial.print("F: "); Serial.println(Frequency);
  //Serial.print("ON: "); Serial.println(ON ? "Yes" : "No");
  //Serial.print("Error: "); Serial.println(error);
  if (error == 1) {
    digitalWrite(BUZZER_PIN, LOW);
    FillScreen();
    alreadyExecuted = false;
  }
  
  if (error == 0) {
    VoltageAlert();
    tone(BUZZER_PIN, 900);
    delay(1000);
  }
  
  if (error == 2) {
    CurrentAlert();
    tone(BUZZER_PIN, 700);
    delay(1000);
  }
}




void inicializaDisplay() {
  if (tema) {
    Color = ST7735_BLACK;
  } else {
    Color = ST7735_WHITE;
  }
  tft.fillScreen(Color);
  int h = 160, w = 128, row, col, buffidx = 0;
  for (row = 0; row < h; row++) {
    for (col = 0; col < w; col++) {
      if (tema) {
        tft.drawPixel(col, row, pgm_read_word(splash_screen_black + buffidx));
      } else {
        tft.drawPixel(col, row, pgm_read_word(splash_screen_white + buffidx));
      }
      buffidx++;
    }
  }
  for (int i = 0; i < 4; i++) {
    tone(BUZZER_PIN, tonee[i]);
    delay(delayy[i]);
    noTone(BUZZER_PIN);
  } 

  tft.fillScreen(Color);

}



void ReciverData() {
  digitalWrite(TRANSMITTER_PIN, HIGH);
  while (!mySerial.available()) {
    delay(10);
  }
  String receivedMessage = mySerial.readStringUntil('\n');
  digitalWrite(TRANSMITTER_PIN, LOW);
  int index = 0;
  char* token = strtok(const_cast<char*>(receivedMessage.c_str()), ",");
  while (token != nullptr) {
    if (index == 0) {
      Voltage_Wire_1 = atof(token); 
    } else if (index == 1) {
      Voltage_Wire_2 = atof(token);
    } else if (index == 2) {
      Current = atof(token);
    } else if (index == 3) {
      Frequency = atof(token);
    } else if (index == 4) {
      ON = atoi(token);
    } else if (index == 5) {
      Wire_1 = atoi(token);
    } else if (index == 6) {
      Wire_2 = atoi(token);
    } else if (index == 7) {
      error = atoi(token);
    }
    token = strtok(nullptr, ",");
    index++;
  }
  Voltage = Voltage_Wire_1 + Voltage_Wire_2;
}



void FillScreen() {
  tft.fillScreen(Color);
  for (int i = 0; i < 8; i++) {
    delay(250);
    if (tema) {
      tft.setTextColor(DarkColors[i]);
    } else {
      tft.setTextColor(LightColors[i]);
    }
    tft.setTextSize(FontSize[i]);
    tft.setCursor(X[i], Y[i]);
    switch (i) {
      case 0:
        tft.println("Versao de testes");
        break;
      case 1:
        tft.fillRect(X[i], Y[i], 30, 10, Color);
        tft.println(String(Voltage, 1) + "V");
        break;
      case 2:
        tft.fillRect(X[i], Y[i], 30, 10, Color);
        if (Current < 11) {
          tft.println(String(Current, 3) + "A");
        } else if ( Current > 10){
          tft.println(String(Current, 2) + "A");
        }
        break;
      case 3:
        tft.fillRect(X[i], Y[i], 30, 10, Color);
        if (Power < 11) {
          tft.println(String(Power, 2) + "W");
        } else if ( Power > 10){
          tft.println(String(Power, 1) + "W");
        } else if (Power > 100){
          tft.println(String(Power, 0) + "W");
        } else if (Power > 1000){
          tft.println(String(Power / 1000, 2) + "Kw");
        }
        break;
      case 4:
        tft.fillRect(X[i], Y[i], 30, 10, Color);
        tft.println(String(Frequency, 1) + "Hz");
        break;
      case 5:
        tft.fillRect(X[i], Y[i], 80, 20, Color);
         if (ValueTotal < 11) {
          tft.println(String(ValueTotal, 2) + "R$/h");
        } else if ( Power > 10){
          tft.println(String(ValueTotal, 1) + "R$/h");
        } 
        break;
      case 6:
        tft.println("Limite de C.");
        break;
      case 7:
        tft.fillRect(X[i], Y[i], 30, 10, Color);
        if (PowerLimitDisplay == true)
          tft.println("ON");
        else {
          tft.setTextColor(ST7735_RED);
          tft.println("OFF");
        }
        break;
    }
    
  }
}



void handleReceberDados() {
  if (server.hasArg("plain")) {
    String dados = server.arg("plain");
    Serial.println(dados);

    DynamicJsonDocument doc(1024);
    deserializeJson(doc, dados);
    bool novoTema = doc["temaJSON"];
    error = doc["errorJSON"];
    PowerLimitDisplay = doc["LimiteJSON"];
    if (novoTema != tema ) {
      gravarValores(novoTema);
      inicializaDisplay();
    }

    server.send(200, "application/json", "{\"status\":\"dados recebidos\"}");
  } else {
    server.send(400, "application/json", "{\"status\":\"erro ao receber dados\"}");
  }
}



void handleEnviarDados() {
  // Criar um objeto JSON para enviar os dados
  DynamicJsonDocument doc(1024);
  doc["tensao"] = Voltage;
  doc["corrente"] = Current;
  doc["frequencia"] = Frequency;
  doc["ligado"] = ON;
  doc["Fio1"] = Wire_1;
  doc["Fio2"] = Wire_2;
  String response;
  serializeJson(doc, response);
  
  server.send(200, "application/json", response);
}



void VoltageAlert() {
  uint16_t ColorText;
  int h = 160, w = 128, row, col, buffidx = 0;
  if (!alreadyExecuted) {
    for (row = 0; row < h; row++) {
      for (col = 0; col < w; col++) {
        if (tema) {
          ColorText = ST7735_WHITE; // Tema claro
          tft.drawPixel(col, row, pgm_read_word(alert_black + buffidx)); 
        } else {
          ColorText = ST7735_BLACK; // Tema escuro
          tft.drawPixel(col, row, pgm_read_word(alert_white + buffidx)); 
        }
      buffidx++;
    }
  }
    tft.setTextColor(ColorText);
    tft.setCursor(22, 115);
    tft.println("Tensao anormal");
    tft.setCursor(20, 135);
    tft.println("Saida desligada");
    
    alreadyExecuted = true;  // Marcar que o código já foi executado
  }

}

void CurrentAlert() {
  uint16_t ColorText;
  int h = 160, w = 128, row, col, buffidx = 0;
  for (row = 0; row < h; row++) {
    for (col = 0; col < w; col++) {
      if (tema == true) {
         tft.drawPixel(col, row, pgm_read_word(alert_black + buffidx));
         ColorText = ST7735_WHITE;
        } else {
          tft.drawPixel(col, row, pgm_read_word(alert_white + buffidx));
          ColorText = ST7735_BLACK;
        }
        buffidx++;
    }
  tft.setTextColor(ColorText);
	tft.setCursor(15,115);
  tft.println("Corrente excedida");
  tft.setCursor(20,135);
  tft.println("Saida desligada");
  }
}




void gravarValores(bool novoTema) {
  // Grava o novo valor do tema se for diferente do atual
  if (novoTema != tema) {
    EEPROM.write(startAddress + enderecoTema, novoTema);
    tema = novoTema;
  }
  // Incrementa o contador de escritas
  writeCounts++;
  // Atualiza o contador de escritas e o endereço inicial na EEPROM
  EEPROM.write(EEPROM_SIZE - 4, startAddress);
  EEPROM.write(EEPROM_SIZE - 2, writeCounts);
  // Salva as alterações na EEPROM
  EEPROM.commit();
}

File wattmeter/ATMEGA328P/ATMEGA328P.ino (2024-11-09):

#include <SoftwareSerial.h>

int dataTransmitterPin = A1;
int powerOffPin = A5;
const int analogPin2 = A2;
const int analogPin3 = A3;
const int currentSensorPin = A0;
const int numSamples = 500;
float voltageRMS2 = 0;
float voltageRMS3 = 0;
float voltageInput2 = 0;
float voltageInput3 = 0;
bool phaseWire1 = false;
bool phaseWire2 = false;
int errorCode = 0;
bool systemON = true;

unsigned long lastUpdateTime = 0;
unsigned long lastZeroCrossingTime = 0;
unsigned long currentTime = 0;
float acFrequency = 0;
bool zeroCrossingDetected = false;

float currentRMS;
float power;
float sensitivity = 0.066;

float calculateCurrent(int sensorSignal);
int currentFilter();

#define TX_PIN 3
#define RX_PIN 7
#define relayPin 2
SoftwareSerial mySerial(RX_PIN, TX_PIN);

void setup() {
  Serial.begin(115200);
  mySerial.begin(115200);
  pinMode(relayPin, OUTPUT);
}

void loop() {
  float dataTransmitterVoltage = analogRead(dataTransmitterPin) * (5.0 / 1023.0);
  float powerOffVoltage = analogRead(powerOffPin) * (5.0 / 1023.0);

  if (powerOffVoltage >= 3.0) {
    digitalWrite(relayPin, HIGH); 
    systemON = false;
  } else {
    systemON = true;
  }
  
  currentRMS = calculateCurrent(currentFilter());

  currentTime = millis();
  uint32_t sumOfSquares2 = 0;
  uint32_t sumOfSquares3 = 0;
  uint16_t adcValue2 = 0;
  uint16_t adcValue3 = 0;
  float avgSquare2 = 0;
  float avgSquare3 = 0;

  if (currentTime - lastUpdateTime >= 1000) {
    for (int i = 0; i < numSamples; i++) {
      adcValue2 = analogRead(analogPin2);
      sumOfSquares2 += (uint32_t)adcValue2 * adcValue2;

      adcValue3 = analogRead(analogPin3);
      sumOfSquares3 += (uint32_t)adcValue3 * adcValue3;

      if ((adcValue2 > 514 || adcValue3 > 514) && !zeroCrossingDetected) {
        unsigned long zeroCrossingTime = micros();
        if (lastZeroCrossingTime != 0) {
          acFrequency = 1000000.0 / (zeroCrossingTime - lastZeroCrossingTime);
        }
        lastZeroCrossingTime = zeroCrossingTime;
        zeroCrossingDetected = true;
      } else if (adcValue2 < 510 && adcValue3 < 510) {
        zeroCrossingDetected = false;
      }

      delayMicroseconds(500);
    }

    avgSquare2 = sumOfSquares2 / (float)numSamples;
    avgSquare3 = sumOfSquares3 / (float)numSamples;

    float rmsADC2 = sqrt(avgSquare2);
    float rmsADC3 = sqrt(avgSquare3);

    voltageInput2 = (rmsADC2 * 5.0) / 1023.0;
    voltageInput3 = (rmsADC3 * 5.0) / 1023.0;
    float realVoltageRMS2 = voltageInput2 * 64.8;
    float realVoltageRMS3 = voltageInput3 * 64.8;
    float totalVoltageRMS = realVoltageRMS3 + realVoltageRMS2;

    if (realVoltageRMS2 > 15) {
      phaseWire1 = true;
    } else {
      phaseWire1 = false;
    }
    if (realVoltageRMS3 > 15) {
      phaseWire2 = true;
    } else {
      phaseWire2 = false;
    }

    if (!(totalVoltageRMS >= 106 && totalVoltageRMS <= 129) && !(totalVoltageRMS >= 211 && totalVoltageRMS <= 234)) {
      errorCode = 1;
      digitalWrite(relayPin, HIGH);
    } else if (currentRMS > 16) {
      digitalWrite(relayPin, HIGH);
      errorCode = 2;
    } else {
      errorCode = 0;
      if (!systemON) {
        digitalWrite(relayPin, HIGH);
      }
    }

    // Serial prints
    Serial.print("Real RMS Voltage: ");
    Serial.print(totalVoltageRMS, 3);
    Serial.println(" V");

    Serial.print("wire1: ");
    Serial.print(voltageInput2, 3);
    Serial.println(" V");

    Serial.print("wire2: ");
    Serial.print(voltageInput3, 3);
    Serial.println(" V");

    //Serial.print(" Wire 1, Phase? ");
    //Serial.println(phaseWire1);

    //Serial.print(" Wire 2, Phase? ");
    //Serial.println(phaseWire2);

    //Serial.print("Is the relay ON? ");
    //Serial.println(systemON);

    Serial.print("Error code? ");
    Serial.println(errorCode);

    Serial.print("AC Frequency: ");
    Serial.print(acFrequency, 2);  
    Serial.println(" Hz");

    Serial.print("Current: ");
    Serial.print(currentRMS, 3);
    Serial.println(" A");

    Serial.print("Power: ");
    Serial.print(totalVoltageRMS * currentRMS, 3);
    Serial.println(" W");

    if (dataTransmitterVoltage >= 3.0) {
      String message = String(realVoltageRMS2) + "," + String(realVoltageRMS3) + "," + String(currentRMS) + "," + String(acFrequency) + "," + String(systemON) + "," + String(phaseWire1) + "," + String(phaseWire2) + "," + String(errorCode);
      mySerial.println(message);
      //Serial.println("Message sent to ESP32");
    }

    lastUpdateTime = currentTime;
  }
}

float calculateCurrent(int sensorSignal) {
  return (float)(sensorSignal) * (5.000) / (1023.000 * sensitivity);
}

int currentFilter() {
  long currentSum = 0, currentAvg;
  for (int i = 0; i < 1000; i++) {
    currentSum += pow((analogRead(currentSensorPin) - 509), 2);
  }
  currentAvg = sqrt(currentSum / 1000);
  if (currentAvg == 1) return 0;
  return currentAvg;
}

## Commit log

2024-05-31 Preparação do ambiente PlataformIO e inclusão de bibliotecas
2024-06-08 Migração para o Arduino IDE
2024-06-09 implementação do controle de brilho e configuração tema claro/escuro
2024-06-10 Implementação das váriaveis do tema e brilho de tela gravadas via EEPROM
    [prototipo.fzz]
2024-06-11 Implementação da atualização da tela splash sem a necessidade de resetar o esp32
    [prototipo.fzz]
2024-06-22 Implementação das telas principais
    [prototipo.fzz]
2024-07-05 Organização das pastas e adição do conceito do banco de dados
2024-10-12 Código de medição e controle do estado da carga finalizado
2024-11-09 Atualização readme.md
    [Lista de Componentes.xlsx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]
2024-11-09 organizção final das pastas
    [Lista de Componentes.xlsx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]
2024-11-11 tentativa de fazer esse código subir
2024-11-11 Tentativa de upload
